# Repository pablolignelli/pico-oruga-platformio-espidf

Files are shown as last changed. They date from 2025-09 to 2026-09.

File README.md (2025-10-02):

# Oruga microcontroller code

This is a Pico-ROS client for the Oruga's ESP32 microcontroller.
## The robot

Oruga is a differential tracked robot for outdoor use. It is based on the [Lynxmotion A4WD3](https://www.lynxmotion.com/a4wd3-rugged-rovers/) platform and has a custom-built ESP32-based control system.

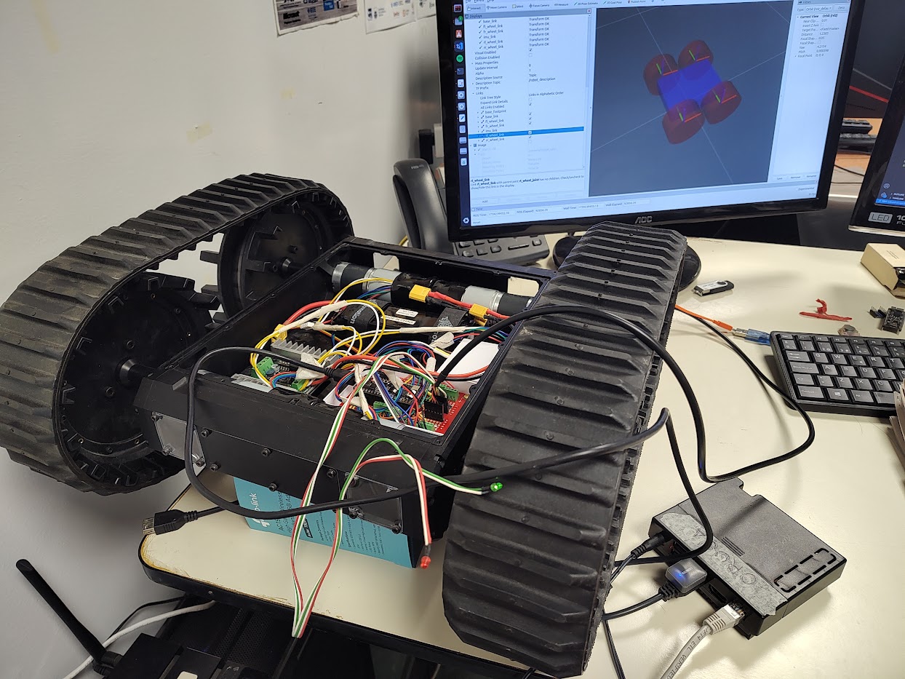
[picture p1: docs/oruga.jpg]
Oruga robot


## Electric schematics

The wiring schematics are in the [docs](docs/) directory. As always, the first movements must be performed with the robot "in the air". If the motor's polarities or encoder directions are reversed, the robot can misbehave violently. It is recommended to run with RViz2 to verify that all directions match: physical motors vs reported odometry and joint rotation in RViz2 (see [oruga_ws](https://github.com/xopxe/oruga_ws) for instructions).

## Instalation

* Open this project in VSCode with Platformio extension installed.

* Install additional dependencies:

```sh
cd .pio/libdeps/pico32
git clone https://github.com/Pico-ROS/Pico-ROS-software.git
```

## Authors and acknowledgment

<jvisca@fing.edu.uy> - [Grupo MINA](https://www.fing.edu.uy/inco/grupos/mina/), Facultad de Ingeniería - Udelar, 2024

## License

Apache 2.0

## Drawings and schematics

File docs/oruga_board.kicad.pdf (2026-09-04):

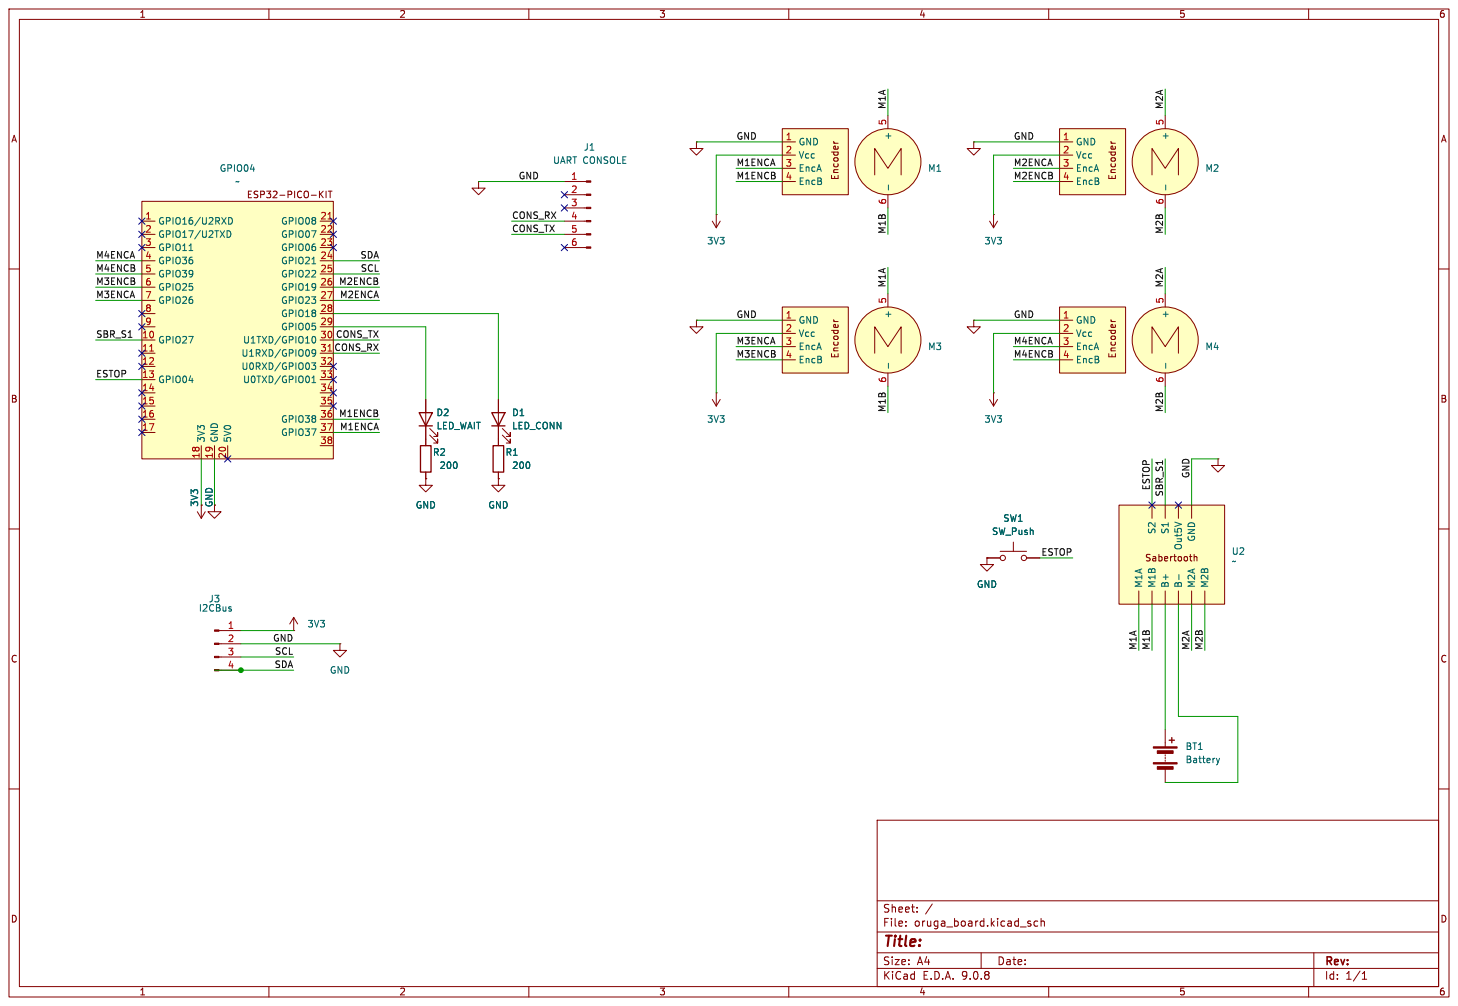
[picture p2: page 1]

- 6 M4 EncoderGND 1 Vcc 2 EncA 3 EncB 4 +

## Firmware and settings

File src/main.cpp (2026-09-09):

#include <freertos/FreeRTOS.h>
#include <freertos/task.h>
#include <stdlib.h>
#include <esp_log.h>
#include <esp_err.h>
#include "driver/i2c_master.h"
#include <nvs_flash.h>
#include "driver/gpio.h"

#define LED_WAIT_PIN GPIO_NUM_5
#define LED_CONN_PIN GPIO_NUM_18
#define I2C0_MASTER_PORT I2C_NUM_0
#define I2C0_MASTER_SDA_IO GPIO_NUM_21
#define I2C0_MASTER_SCL_IO GPIO_NUM_22

#define I2C0_MASTER_CONFIG_DEFAULT {           \
    .i2c_port = I2C0_MASTER_PORT,              \
    .sda_io_num = I2C0_MASTER_SDA_IO,          \
    .scl_io_num = I2C0_MASTER_SCL_IO,          \
    .clk_source = I2C_CLK_SRC_DEFAULT,         \
    .glitch_ignore_cnt = 7,                    \
    .flags = {.enable_internal_pullup = true}, \
}

///////////////////////////////////////////////////////////////////////////
// initialize master i2c 0 bus configuration
i2c_master_bus_config_t i2c0_bus_cfg = I2C0_MASTER_CONFIG_DEFAULT;
i2c_master_bus_handle_t i2c0_bus_hdl;

// #define WIFI_SSID ""
#define WIFI_PASSWORD ""

// #define ZENOH_ROUTER_ADDRESS "tcp/192.168.10.235:7447"
// #define ZENOH_ROUTER_ADDRESS "tcp/192.168.101.2:7447"
// #define ZENOH_ROUTER_ADDRESS "serial/UART_0#baudrate=115200"
#define ZENOH_ROUTER_ADDRESS "serial/UART_0#baudrate=921600"

#define ZENOH_NODE_NAME "pico_oruga"

#define ROS_DOMAIN_ID 100
///////////////////////////////////////////////////////////////////////////

#if defined(WIFI_SSID)
#include "wifi_connection.h"
WifiConnection wifi;
#endif

#include "picorosso.h"
PicoRosso picorosso;

#include "picorosso_bme680.h"
EnvBME680 env;

#include "picorosso_mpu6050.h"
ImuMPU6050 imu;

#include "mobility_skid.h"
MobilitySkid mobility;

#include "infrastructure.h"
#define EMERGENCY_STOP_BUTTON_PIN GPIO_NUM_4
#define BATTERY_VOLTAGE_READER_PIN GPIO_NUM_32

static void on_emergency_stop(bool stopped) {
    mobility.set_motor_enable(!stopped);
}

#include "ticker.h"
Ticker ticker;

#if defined(WIFI_SSID)
void InitNVS()
{
    esp_err_t ret = nvs_flash_init();
    if (ret == ESP_ERR_NVS_NO_FREE_PAGES || ret == ESP_ERR_NVS_NEW_VERSION_FOUND)
    {
        ESP_ERROR_CHECK(nvs_flash_erase());
        ret = nvs_flash_init();
    }
    ESP_ERROR_CHECK(ret);
}
#endif

extern "C"
{
    void app_main(void);
}

void app_main()
{
    ESP_LOGI("main", "Booting...");

    gpio_config_t io_conf_wait = {
        .pin_bit_mask = (1ULL << LED_WAIT_PIN), // Select GPIO
        .mode = GPIO_MODE_OUTPUT,               // Set as output
        .pull_up_en = GPIO_PULLUP_DISABLE,      // Disable pull-up
        .pull_down_en = GPIO_PULLDOWN_DISABLE,  // Disable pull-down
        .intr_type = GPIO_INTR_DISABLE          // Disable interrupts
    };
    gpio_config(&io_conf_wait);
    gpio_set_level(LED_WAIT_PIN, 1);

    gpio_config_t io_conf_conn = {
        .pin_bit_mask = (1ULL << LED_CONN_PIN), // Select GPIO
        .mode = GPIO_MODE_OUTPUT,               // Set as output
        .pull_up_en = GPIO_PULLUP_DISABLE,      // Disable pull-up
        .pull_down_en = GPIO_PULLDOWN_DISABLE,  // Disable pull-down
        .intr_type = GPIO_INTR_DISABLE          // Disable interrupts
    };
    gpio_config(&io_conf_conn);
    gpio_set_level(LED_CONN_PIN, 0);

// Start NVS and Wifi
#if defined(WIFI_SSID)
    InitNVS();
    wifi.connect(WIFI_SSID, WIFI_PASSWORD);
    while (wifi.connected == false)
    {
        vTaskDelay(pdMS_TO_TICKS(50));
    }
#endif

    // Start I2C
    /* instantiate i2c master bus 0 */
    ESP_ERROR_CHECK(i2c_new_master_bus(&i2c0_bus_cfg, &i2c0_bus_hdl));

    // PicoRosso initalization //////////////////////////////
    picorosso.setup(ZENOH_NODE_NAME, ZENOH_ROUTER_ADDRESS, ROS_DOMAIN_ID);
    gpio_set_level(LED_CONN_PIN, 1);

    // Modules initalization ////////////////////////////////
    ticker.setup("tick");
    env.setup(i2c0_bus_hdl);
    imu.setup(i2c0_bus_hdl);
    Infrastructure::setup(EMERGENCY_STOP_BUTTON_PIN, on_emergency_stop);
    Infrastructure::setup(EMERGENCY_STOP_BUTTON_PIN, on_emergency_stop, BATTERY_VOLTAGE_READER_PIN);
    mobility.setup();

    // Publisher task
    // xTaskCreate(publish_twist, "publish_twist_task", 4096, NULL, 1, NULL);

    gpio_set_level(LED_WAIT_PIN, 0);
    ESP_LOGI("main", "Booting completed.");

    while (true)
    {
        TickType_t last_wake_time = xTaskGetTickCount();

        picorosso.rosout.out("Alive!", __FILE__, __func__, __LINE__, ROSLOG_INFO);
        vTaskDelayUntil(&last_wake_time, pdMS_TO_TICKS(60000));
    }
}

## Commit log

2025-09-18 Zenoh through uart0, logs through uart1
2025-09-18 wip mpu6050 imu support
2025-09-18 wip imu mpu6050
2025-09-21 udev for the esp32
2025-09-21 seaparte serialization buffers per-thread
2025-09-24 Fix clok ticks usage
    [main.cpp]
2025-09-24 add schematics
    [oruga_board.kicad_sch]
2025-09-27 mobility and motot control reworked
    [main.cpp]
2025-09-29 Boot status led support
2026-08-30 feat(infrastructure): add emergency stop button
2026-09-02 chore(docs): update schematics
    [oruga_board.kicad_sch]
2026-10-16 fix(infrastructure): keep e-stop task handle and drop duplicate setup
    The battery reader task was created with &emergency_stop_task_handle,
    overwriting it, so the e-stop ISR woke the battery task instead of the
    button task and the emergency stop never fired. main.cpp also still
    called the old setup() signature, which no longer compiled.
2026-10-16 fix(infrastructure): configure the battery ADC correctly
    - Disable ULP mode: ESP32 has no RISC-V ULP, so adc_oneshot_new_unit()
    failed and ESP_ERROR_CHECK aborted the firmware at boot.
    - Calibrate the unit the pin is on instead of hardcoding ADC_UNIT_1, and
    fall back to a 1100 mV Vref when the eFuse has none.
    - Stop enabling the internal pull-down on the ADC pin, which loaded the
    divider and skewed readings.
    - Report setup errors instead of aborting, and average 16 samples per
    reading.
2026-10-16 feat(infrastructure): publish battery voltage as sensor_msgs/BatteryState
    The reader task only logged the ADC value; it is now converted to the
    battery voltage via a configurable divider ratio and published on
    infrastructure/battery. The task is started after the publisher is
    declared, and the unused notify_battery_voltage() is removed.
2026-10-16 fix(main): set battery divider ratio for the 47k/10k divider
